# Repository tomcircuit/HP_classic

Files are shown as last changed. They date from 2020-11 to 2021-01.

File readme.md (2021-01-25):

# HP_classic - LiPo Battery for HP 'Classic' Calculators - Version 2
 
This is my attempt at a LiPo-based battery pack for "Classic" HP Calculators, specifically HP-35, HP-45, and HP-55.  The original NiCd packs are all dead by now, and rebuilding them is difficult - *assuming you can even find a pack to rebuild*. I thought it would be fun to use a rechargeable LiPo battery, and include the circuitry to re-charge via USB as well. 

> LiPo chemistry has very specific care-and-feeding when it comes to recharging, **you cannot use the HP AC charger to recharge this pack!**  Don't even try it with Version 1 of this project!

**UPDATE**: Version 2 design includes *Charger Immunity* circuitry to prevent mayhem if the HP AC  charger is connected. 

The basic idea is to use a gold-flashed (ENIG) PCB as the contact substrate, and mount the LiPo, USB micro B receptacle, and charging circuitry on the opposite side. The 'charger immunity' introduced in Version 2 is placed on the same side as the contact pads, but in areas where there will be no mechanical interference. A pair of laser-cut 'endcaps' locate the assembly within the battery well and allow the compartment cover to hold it in place. 
 
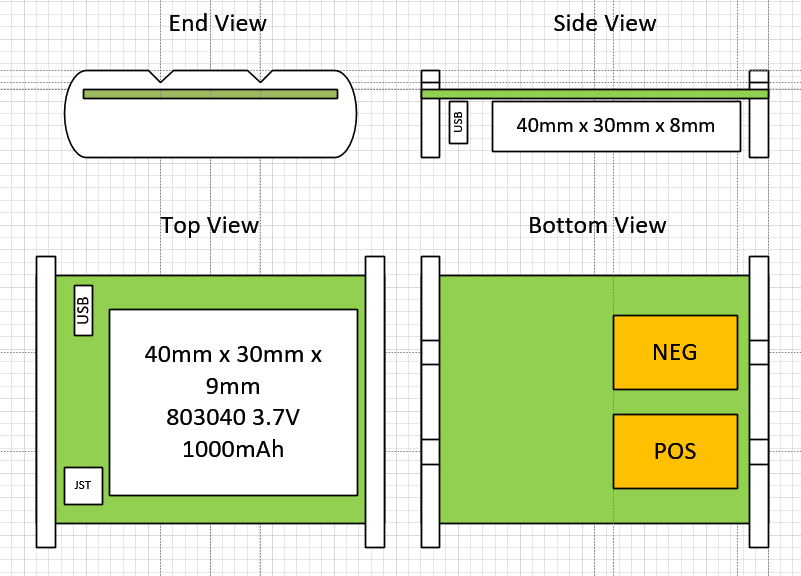
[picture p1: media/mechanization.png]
Mechanization


## The Endcaps
I just happen to have an original NiCd HP battery pack, so I was able to measure its end profile and draw it in MS Visio and export as an SVG file. The endcap is laser-cut from 3mm thick fiberboard and its overall size is **47mm x  14mm**. I'm sure you could use some other material if you desired. I went with fiberboard in case I needed to tweak it, and because it is cheap. Two endcaps are required for each pack. 

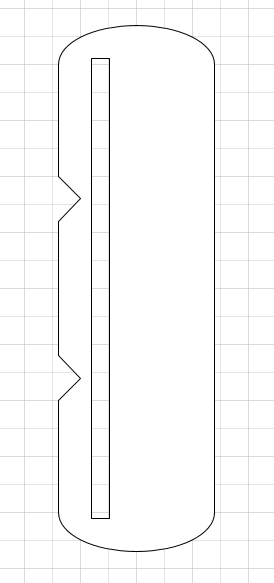
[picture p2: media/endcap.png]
Laser Cut Endcap


I had a batch of 6 pcs made by [Ponoko](https://www.ponoko.com/) and they were very inexpensive, less than $1 each. Consider that Ponoko has a flat $14 setup charge per design, however. If you have other means to access a laser cutter, you can probably do this much more cheaply.

## The PCB 
The PCB holds the USB micro B connector, the charging circuitry, the protection circuitry, a connector for the LiPo battery, and most importantly the pads that mate with the contacts in the calculator.  The overall size of the PCB is 56mm x 40mm. The material is 1.6mm thick FR4. So that the contact pads do not  tarnish over time, I chose a gold-flash treatment (ENIG). 

The schematic and PCB were designed using KiCAD. Note that the PCB can accommodate either a JST or 0.1" two pin battery connector type.

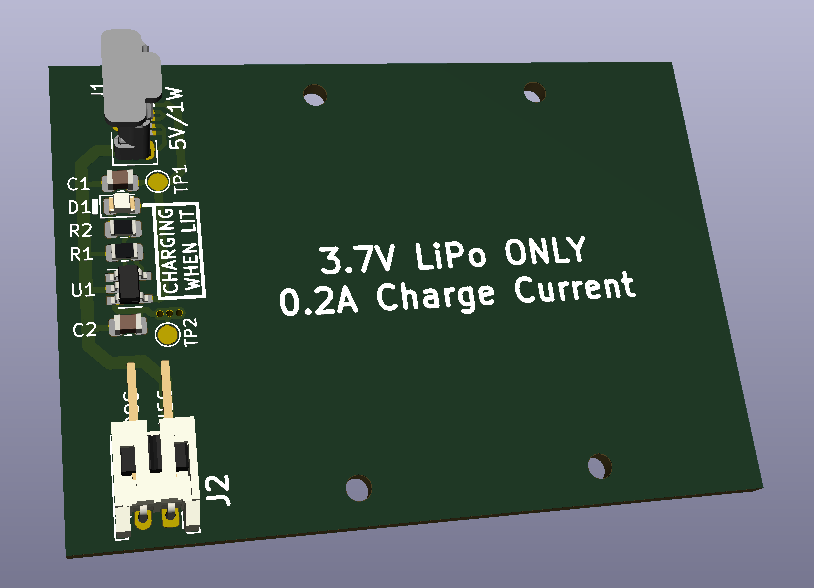
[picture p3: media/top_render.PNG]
3D render of PCB V2 top


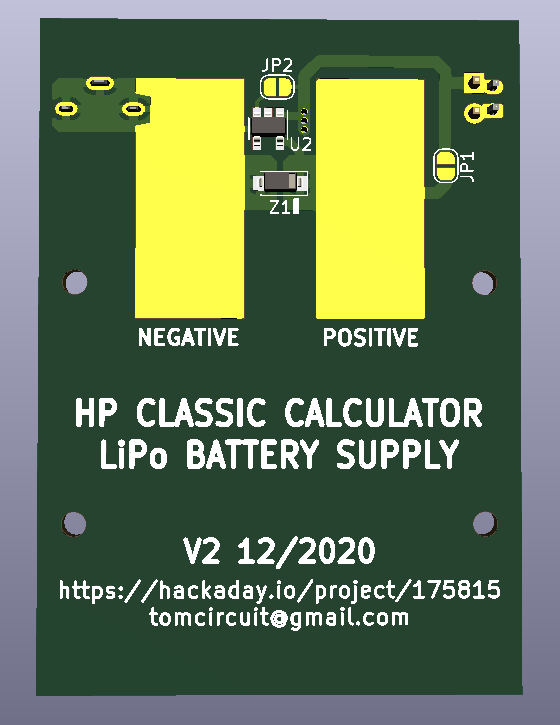
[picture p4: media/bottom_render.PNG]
3D render of PCB V2 bottom


I had the V1 PCB fabricated by [PCBWay](https://www.pcbway.com/)  This was the second PCB that I've had made by them, and I am once again very satisfied with the speed, quality, and price. The PCB can be ordered from them directly as a [shared project](https://www.pcbway.com/project/shareproject/HP_Classic_Calculator_LiPo_Battery_Pack.html). 

UPDATE: I will have the V2 PCB fabricated there, as well, and include a link when it's available.

## The LiPo Battery
I wanted a 1S (3.7V) LiPo battery in the neighborhood of 1000mAhr that would fit within the confines of the original pack envelope. This led me to a size "803040" LiPo battery. I prefer the JST connector, so I found one with that connector type. The PCB can accommodate either JST or "two pin" connectors, so there's some flexibility here. 

I believe that a thicker battery could be used, because of the profile of the battery compartment cover. That might allow for a higher capacity battery, which would translate into longer running time. 

**UPDATE**: I founda  1200mAhr LiPo battery in size "103040" that is just 2mm thicker. I've ordered some to try out.  20% more capacity is always good, right?

## Putting It All Together
Pretty self-explanatory. I used 0805 size components to allow for easy hand-soldering. Note that D1 is an LED and is polarized, so pay attention to that. Soldering the USB connector requires a fine-tip iron and some patience. 

The endcaps each need a small amount of Krazy glue to keep them in place, and the PCB edges should be flush with the outer surface of each endcap to match the overall size of the original battery pack.
> You will not be able to access the USB connector's solder joints after the endcap is installed, so be sure of your workmanship there before you glue that particular endcap in place

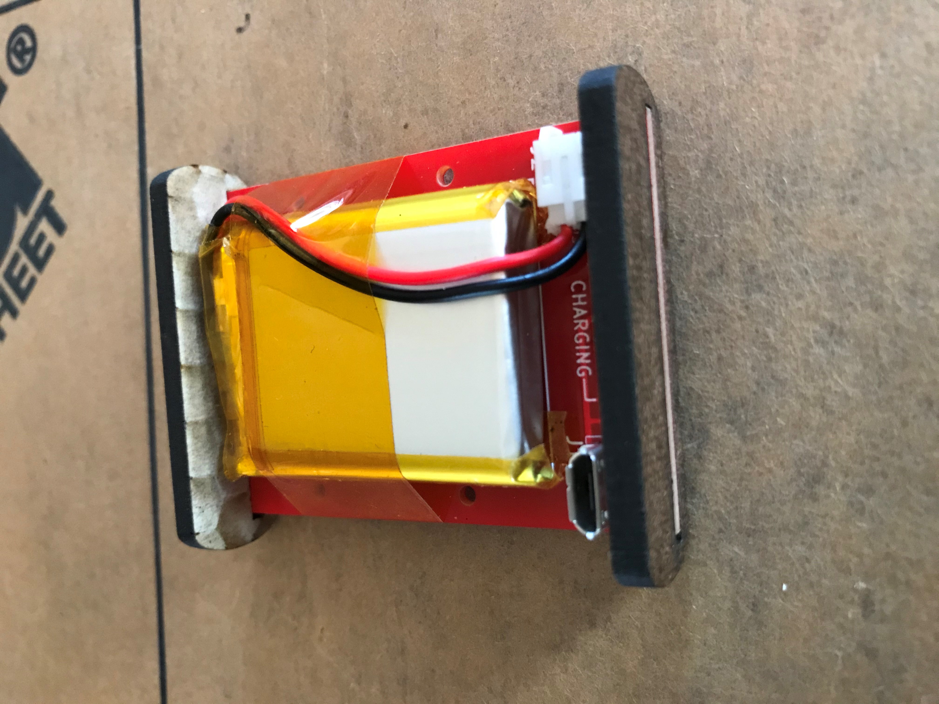
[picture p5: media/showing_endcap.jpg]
Assembly showing endcap


**UPDATE**: I've rotated the USB connector 180degrees on PCB V2, so that the solder joints can be accessed even after the endcap is glued on. It's still a good idea to wait until everything is tested before gluing on the endcaps, though.

I don't know if there are 'standards' for LiPo battery connector polarity, but I managed to get a battery that had the opposite pinning than what I expected. I had to swap the polarity of the battery plug to make it match PCB V1 pinout. Plug the battery in and tape it to the PCB. 

**UPDATE**: I've swapped the JST connector pins on PCB V2 so that they agree with all of the LiPo batteries that I could find photos of on the web.  This should make life easier for everyone in the future.

## Charge It
Connect a micro-B cable to the board and charge the LiPo battery. The LED will stay lit during the charging process, and extinguish when it is completed. The charge current is about 200mA (0.2C for a 1000mAhr battery). You can adjust R1 to change the current if you need to. It took about two hours to charge my battery,

## Use It!
Install the pack into the calculator, paying attention to mate the contact pads with the contacts in the calculator. The pads are sized to prevent contact if the pack is inserted incorrectly, but I do not recommend testing to find out if I got that all right or not. My understanding is that these classic calculators will not withstand reverse voltage. Don't risk it.
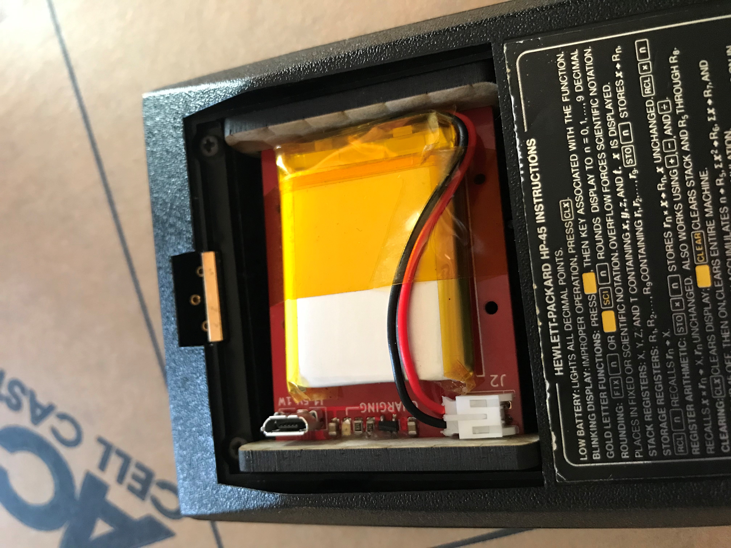
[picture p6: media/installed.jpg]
Installed Pack


If you've done everything correctly, you should be greeted with 0.00 when you turn your calculator on. Your classic calculator is now sipping power from a modern, convenient, and most importantly *non-leaking* battery pack.  Enjoy!

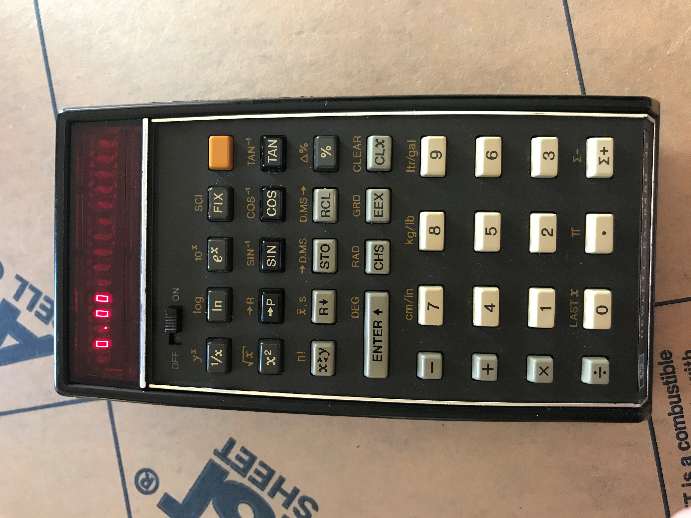
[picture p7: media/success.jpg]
Happy HP45


December 2, 2020
Tom LeMense
rev 2
<!--stackedit_data:
eyJoaXN0b3J5IjpbLTIzMjk3MDczOF19
-->

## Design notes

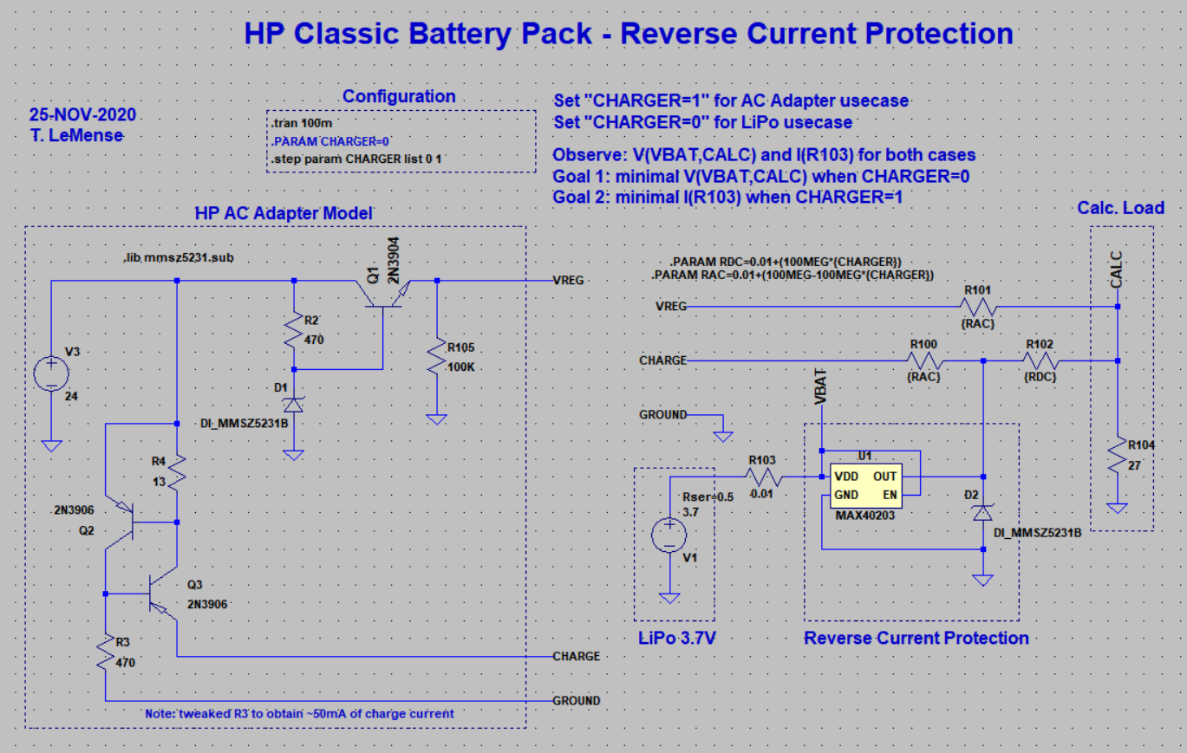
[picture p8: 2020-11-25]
simulation/schematic.png

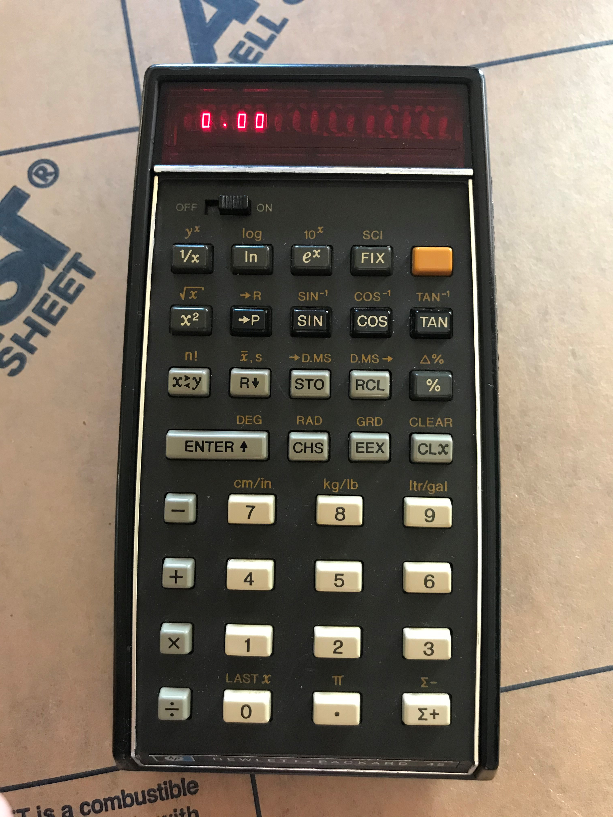
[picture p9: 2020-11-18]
media/success_rot.jpg

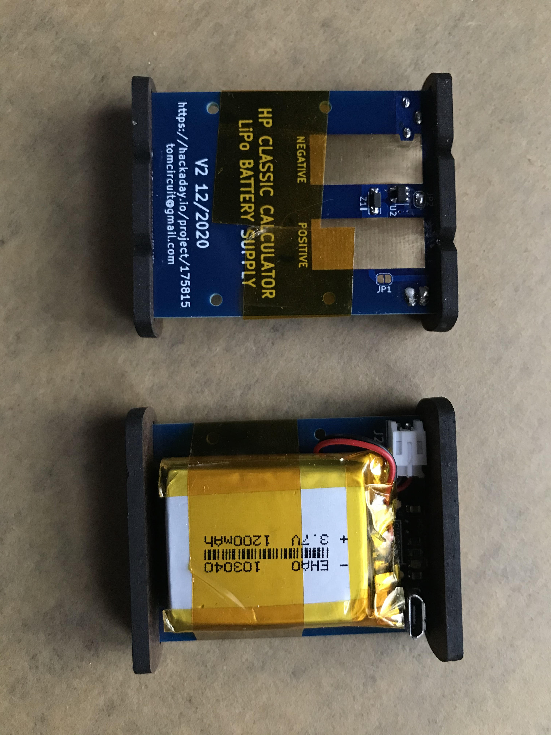
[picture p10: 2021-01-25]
media/v2_packs1.jpg

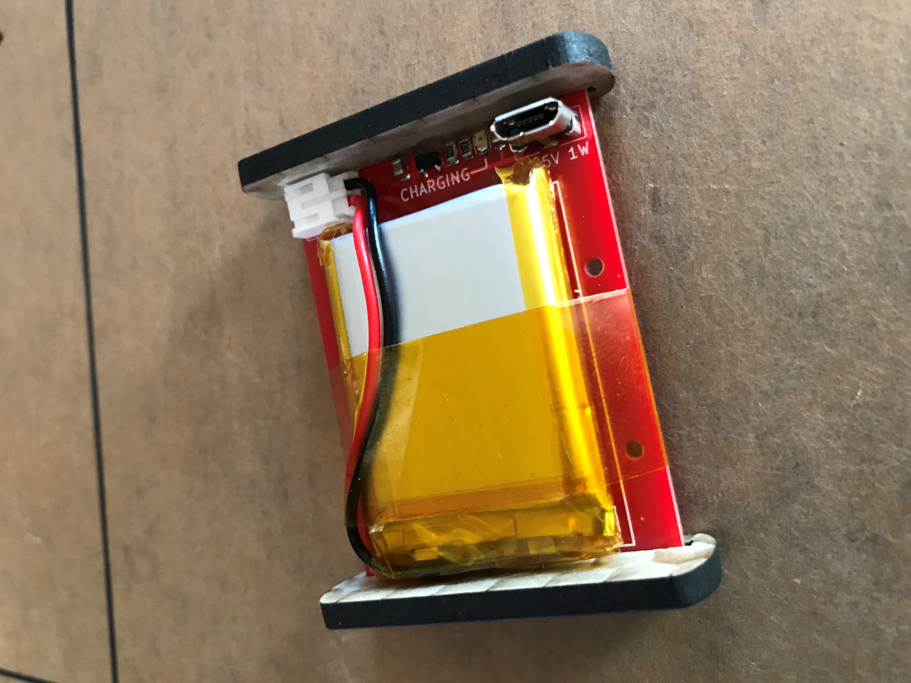
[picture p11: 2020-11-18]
media/top_oblique.jpg

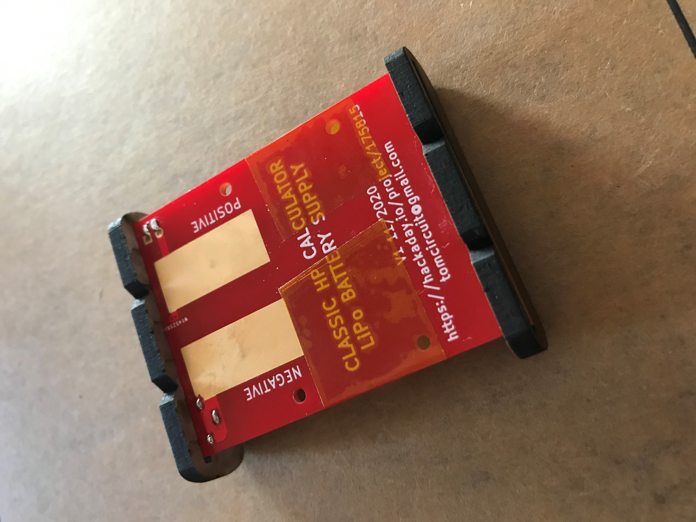
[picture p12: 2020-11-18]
media/under_oblique.jpg

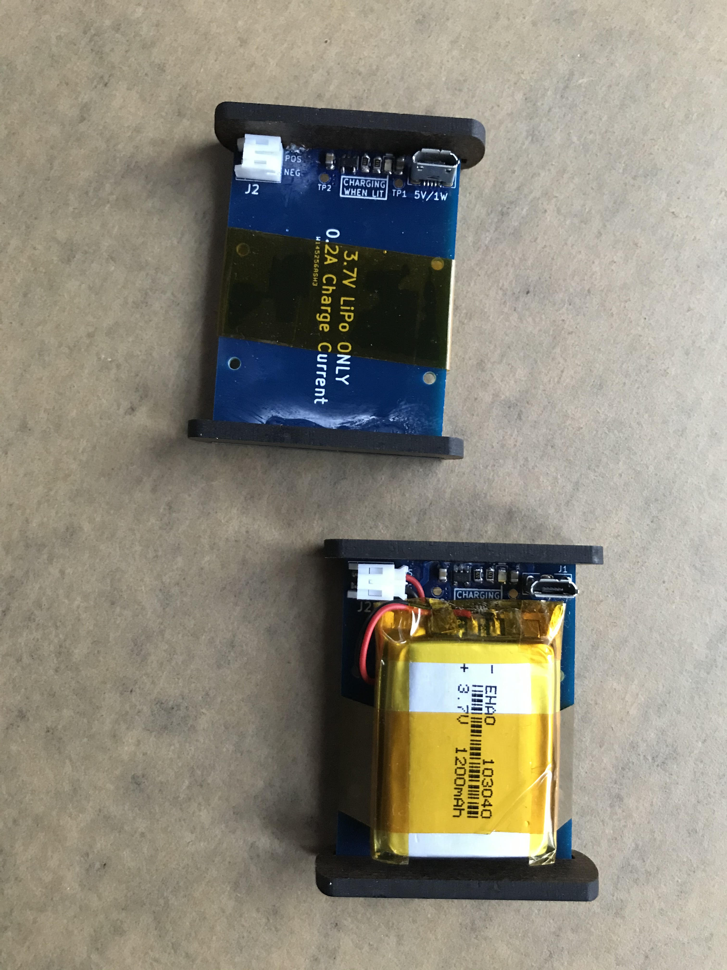
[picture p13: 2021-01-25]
media/v2_packs2.jpg

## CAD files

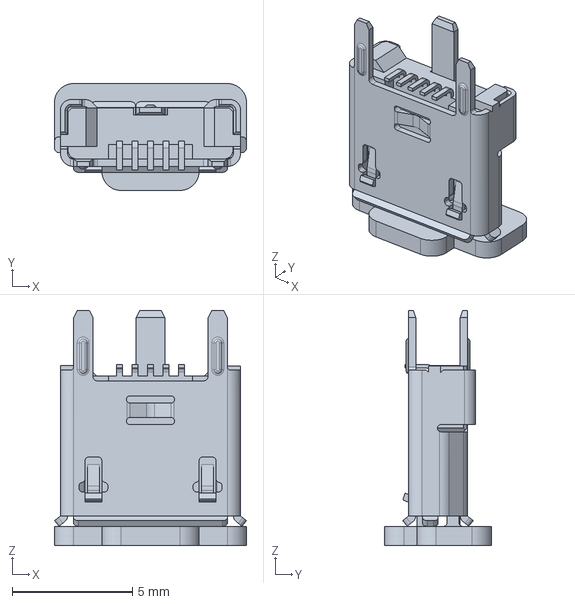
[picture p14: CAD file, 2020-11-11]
electrical/105133-0011_stp/1051330011.stp
8.00 x 4.45 x 9.78 mm

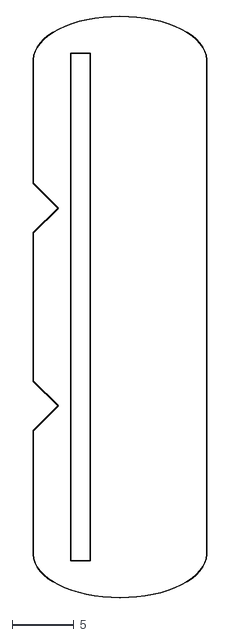
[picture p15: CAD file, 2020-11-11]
Mechanical/20201103_Classic_HP_mechanical.dxf
14.0 x 47.0

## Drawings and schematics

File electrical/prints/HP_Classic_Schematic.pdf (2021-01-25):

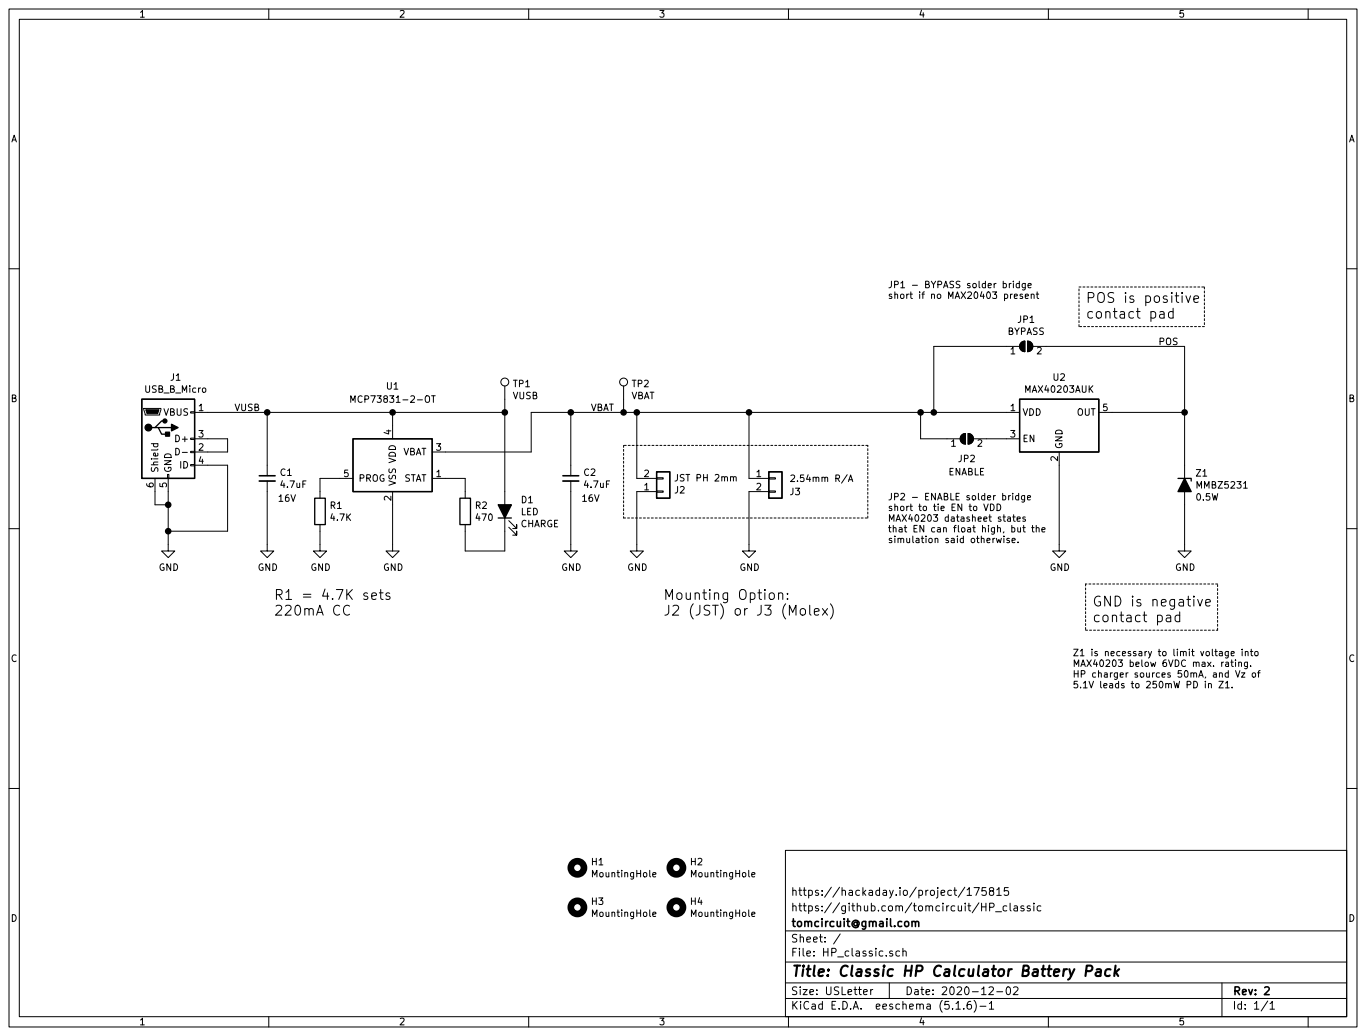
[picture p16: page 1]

HP charger sources 50mA, and Vz of 5.1V leads to 250mW PD in Z1. POS is positive
contact pad

simulation said otherwise. JP1 - BYPASS solder bridge
short if no MAX20403 present

JP2 - ENABLE solder bridge
short to tie EN to VDD MAX40203 datasheet states

that EN can float high, but the

https://hackaday.io/project/175815 H2MountingHole GND

Z1 is necessary to limit voltage into
MAX40203 below 6VDC max. rating.

https://github.com/tomcircuit/HP_classic
File: HP_classic.sch Sheet: / tomcircuit@gmail.com

Id: 1/1 Title: Classic HP Calculator Battery Pack

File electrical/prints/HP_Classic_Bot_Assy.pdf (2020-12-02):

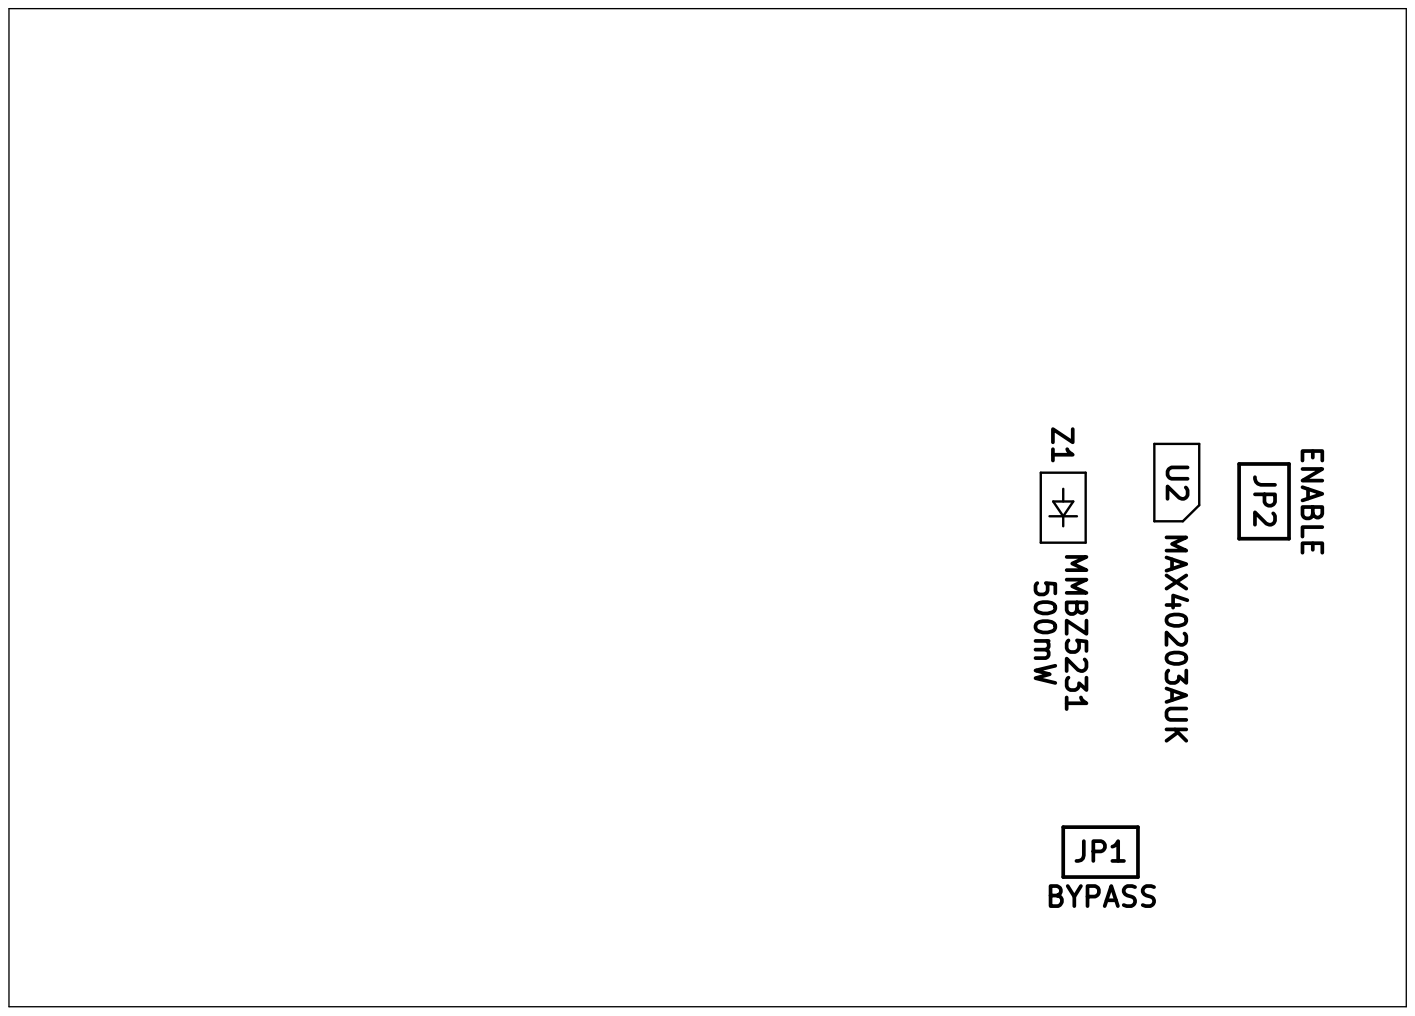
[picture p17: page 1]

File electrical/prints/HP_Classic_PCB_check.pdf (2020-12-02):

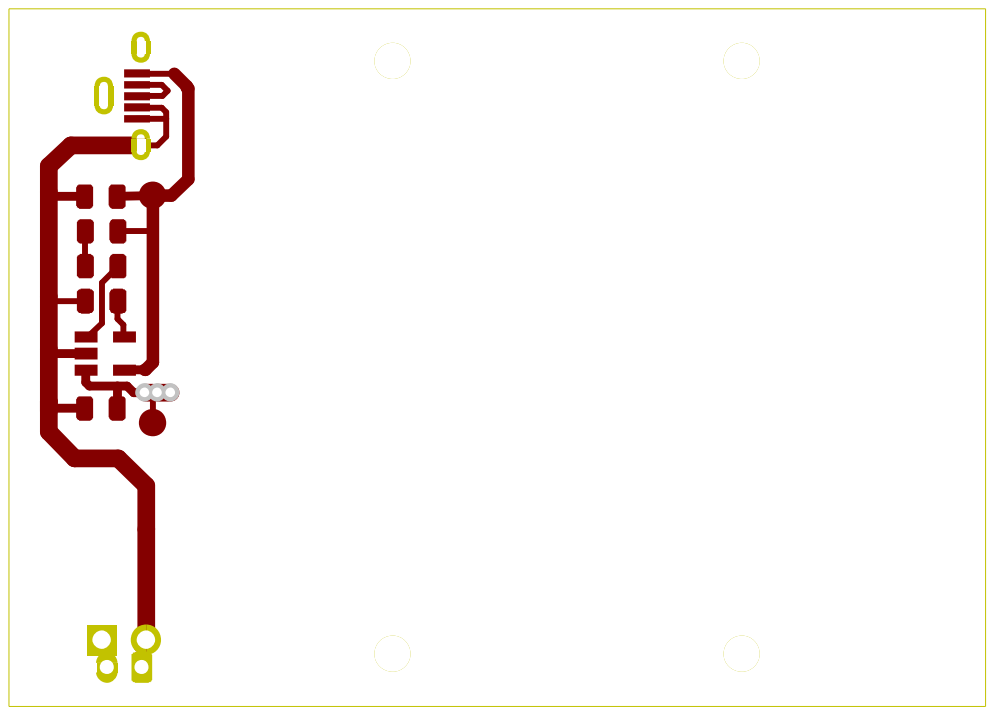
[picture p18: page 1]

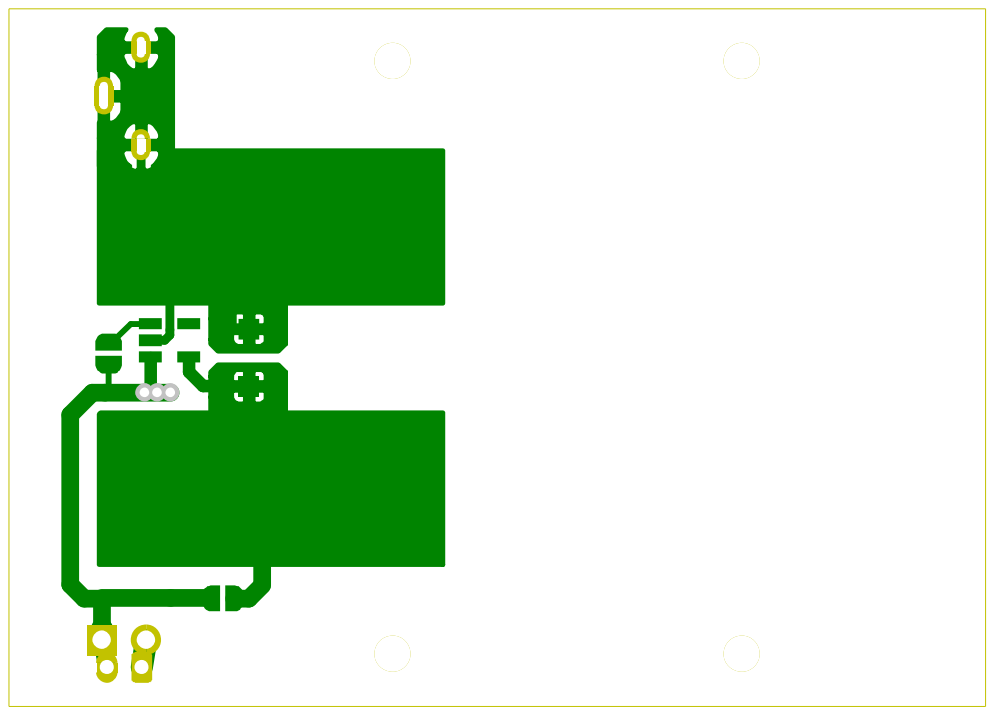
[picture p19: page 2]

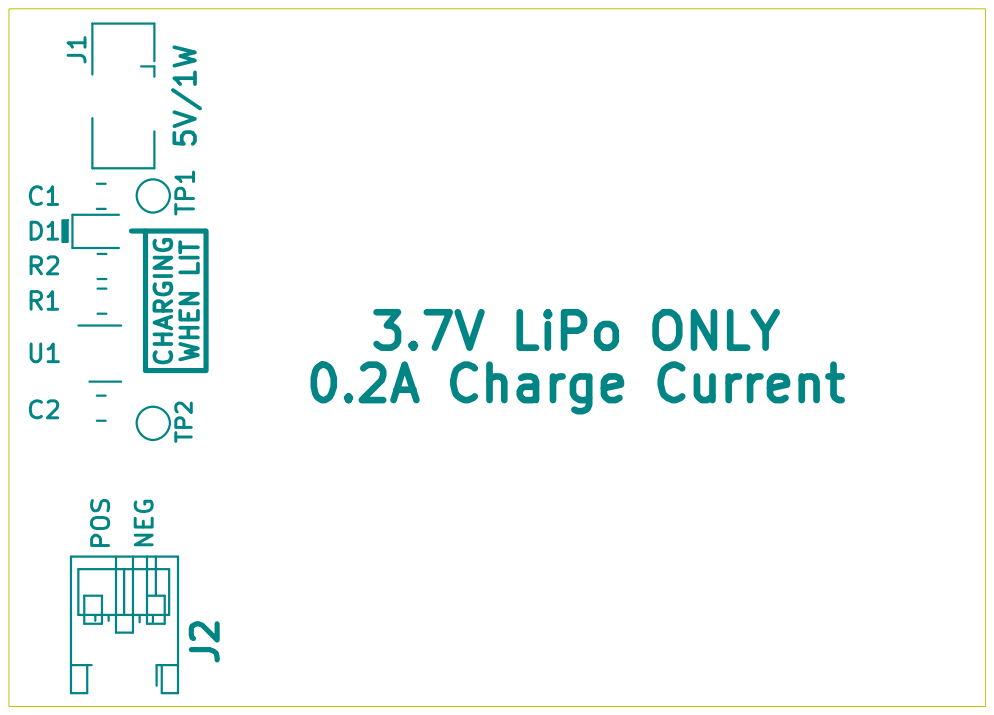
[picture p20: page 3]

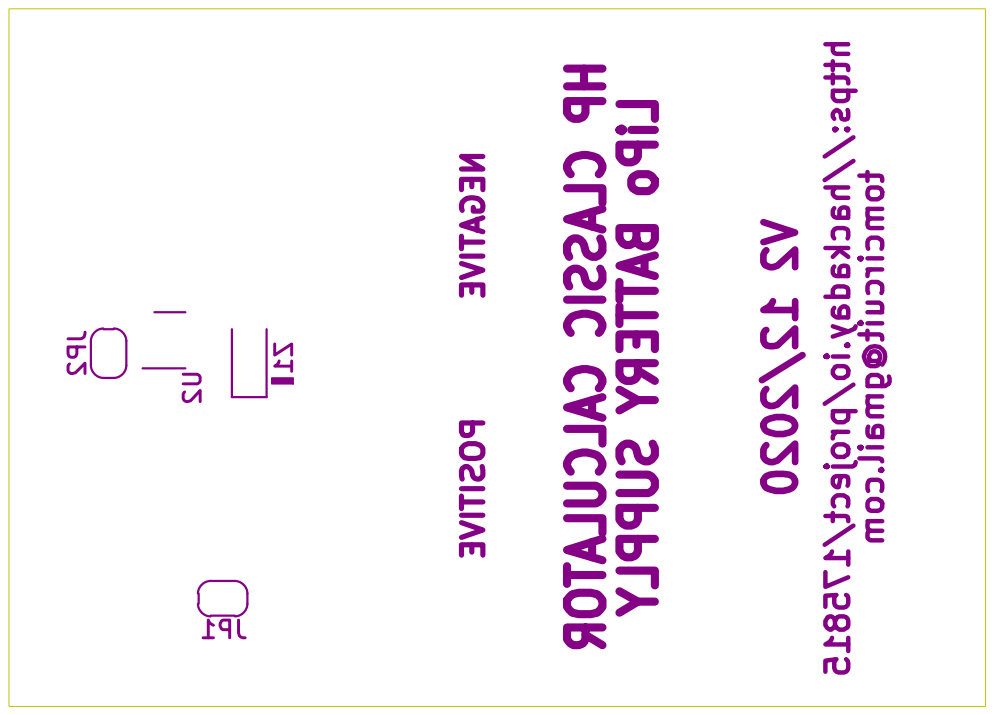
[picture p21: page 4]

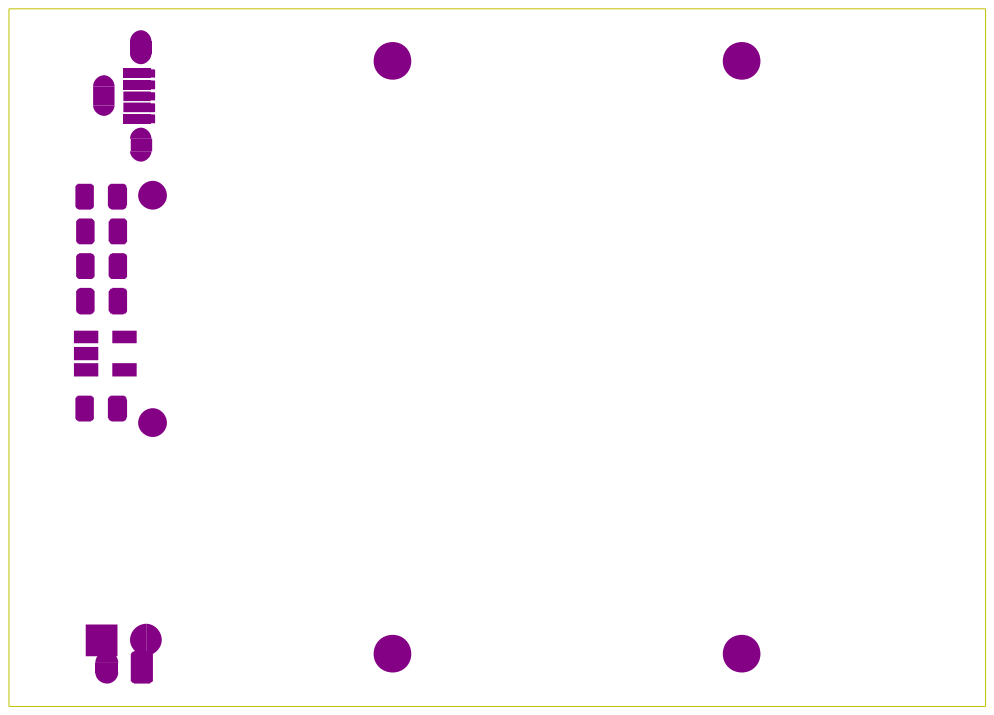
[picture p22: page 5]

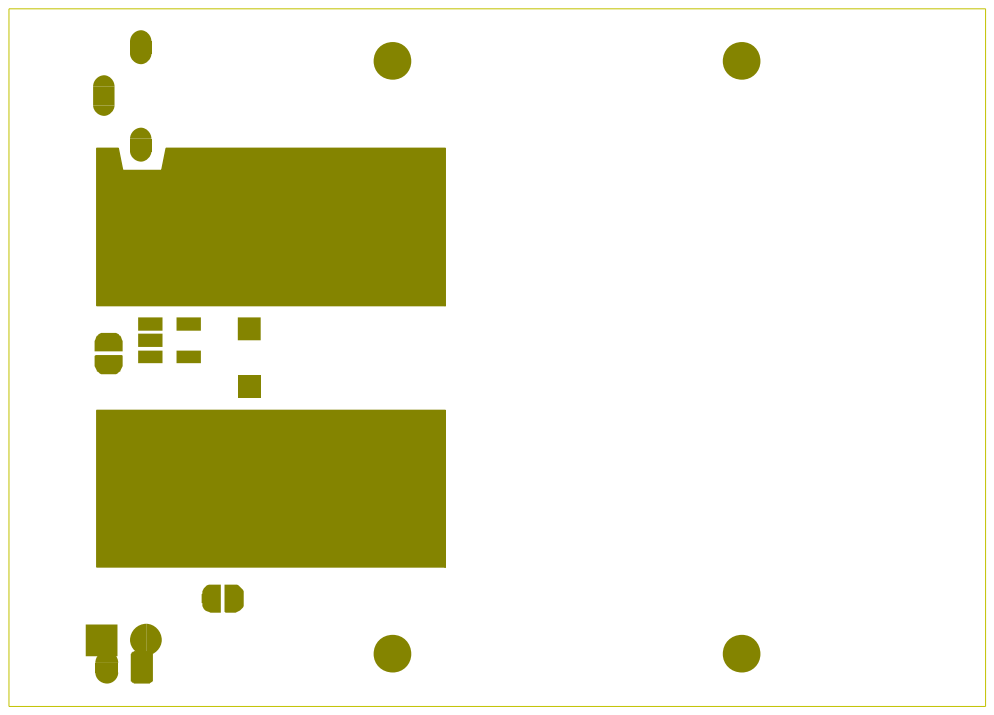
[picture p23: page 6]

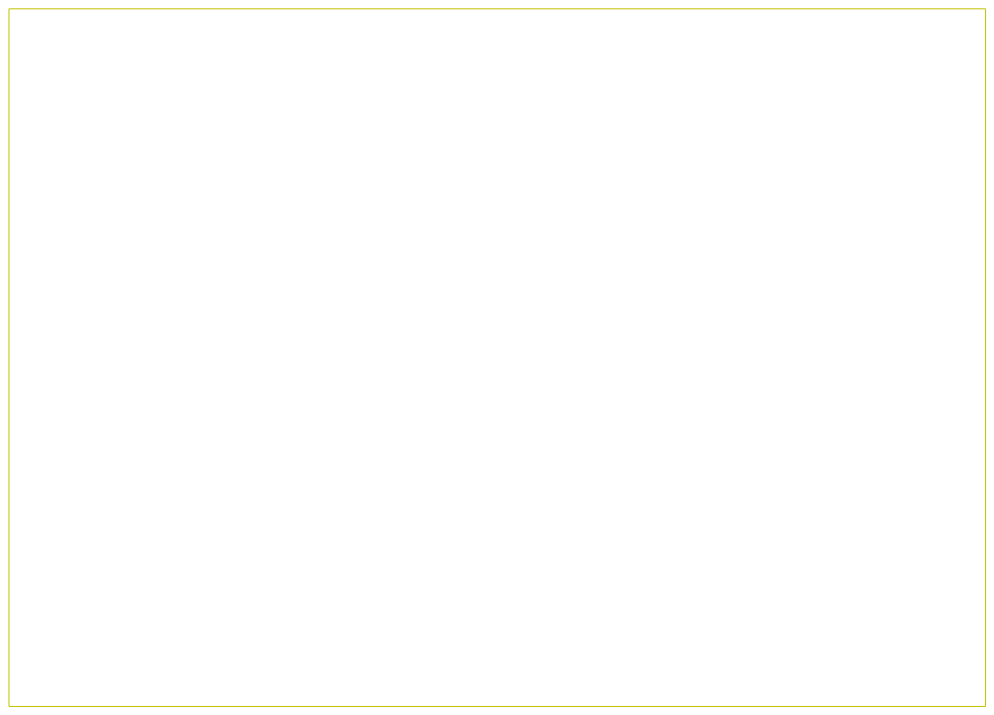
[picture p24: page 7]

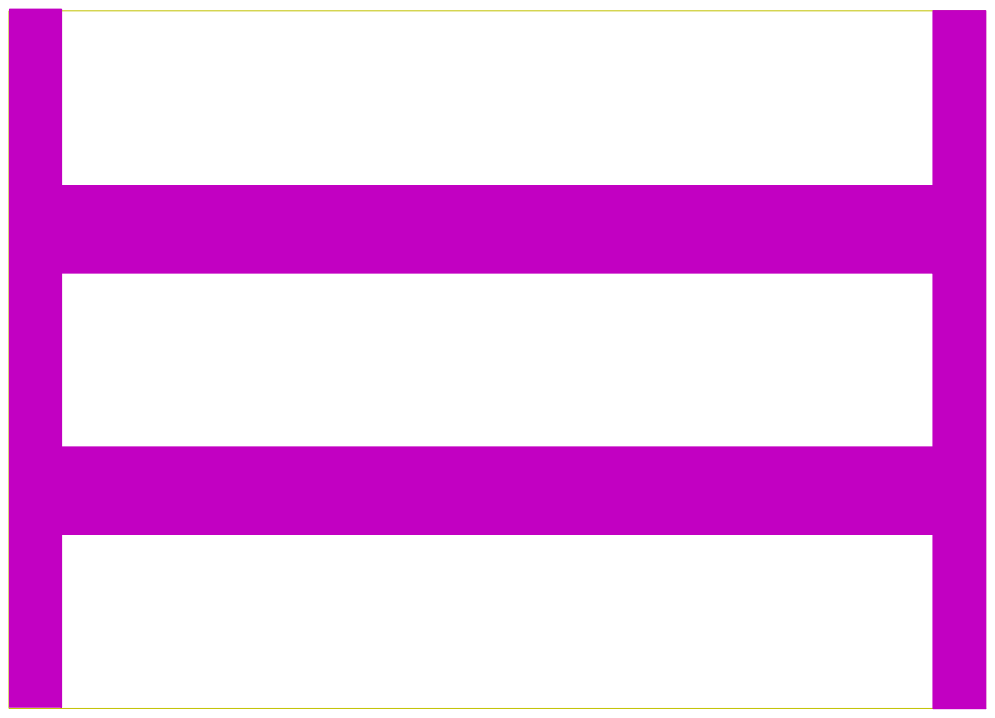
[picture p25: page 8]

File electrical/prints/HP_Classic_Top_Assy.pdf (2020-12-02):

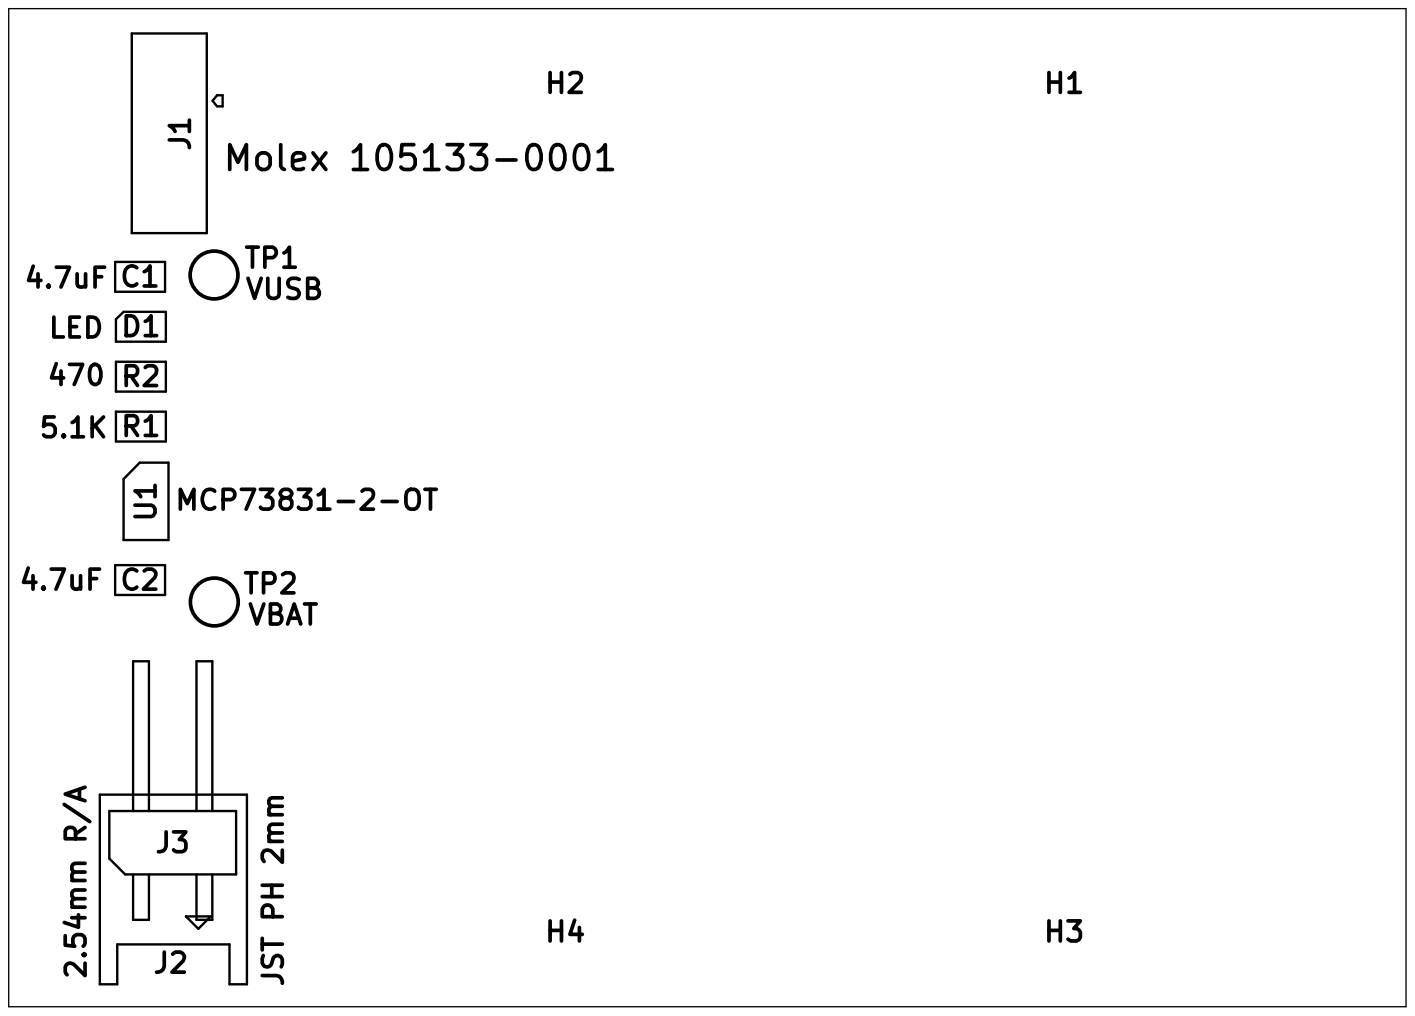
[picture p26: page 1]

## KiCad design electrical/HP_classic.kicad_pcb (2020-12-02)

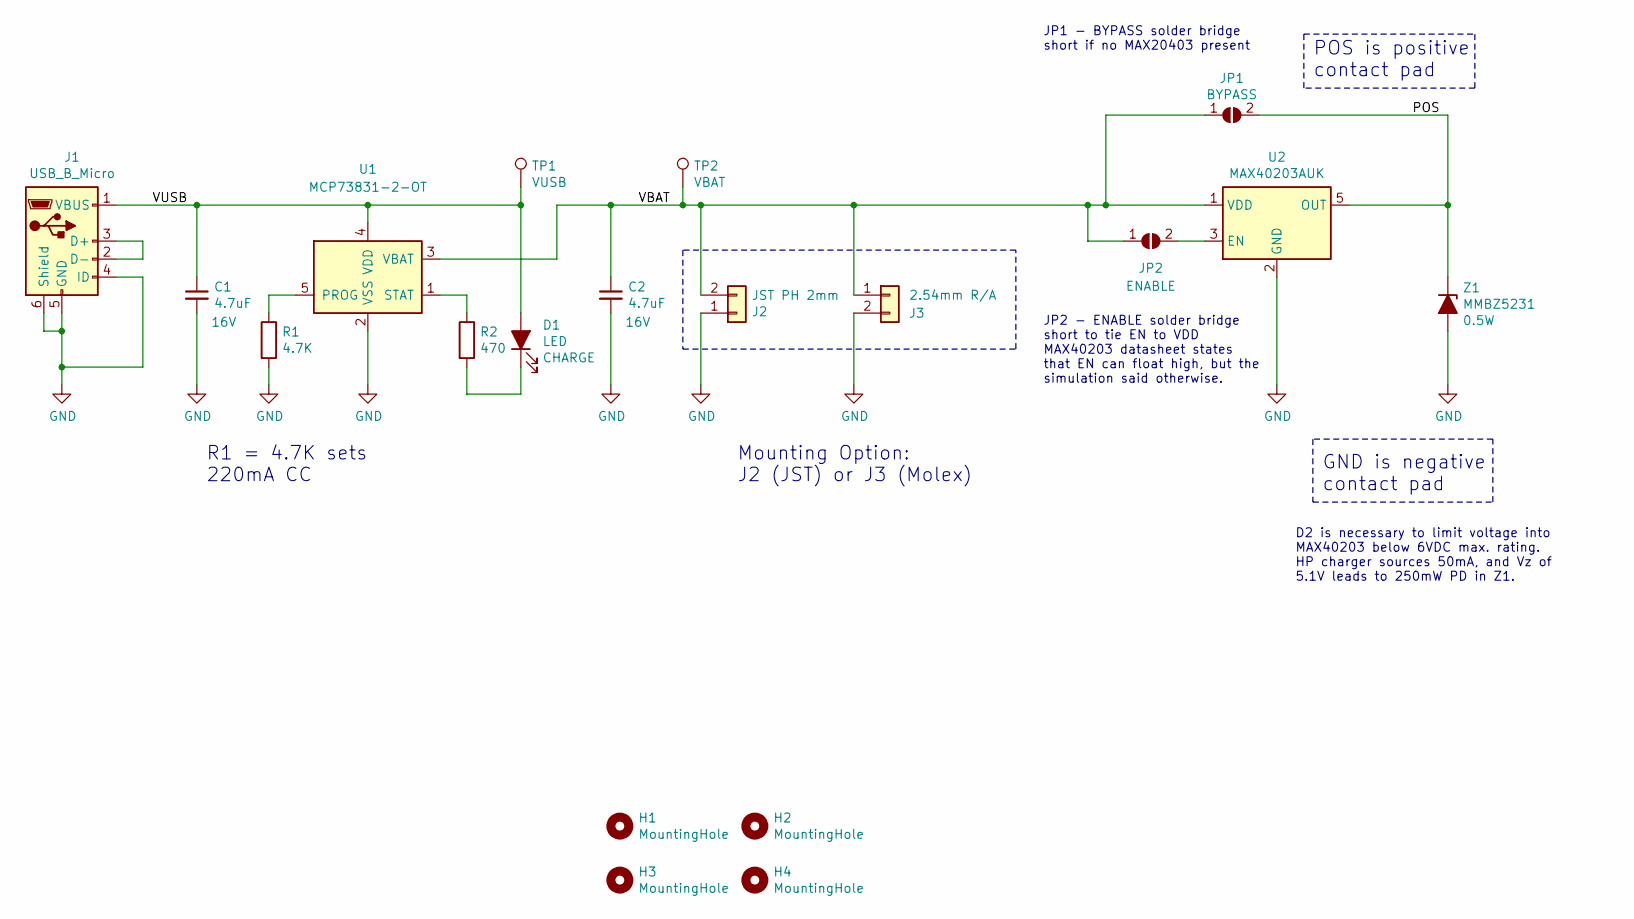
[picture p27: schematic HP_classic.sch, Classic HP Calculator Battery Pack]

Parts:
C1, C2: 4.7uF; C_0805_2012Metric; MPN MuRata GRM21BR71C475KE51L; DigiKey 490-14466-1-ND
D1: LED; LED_0805_2012Metric
H1, H2, H3, H4: MountingHole; MountingHole_2mm
J1: USB_B_Micro; USB_Micro-B_Molex-105133-0001; MPN Molex 1051330011; DigiKey WM10134CT-ND
J2: JST PH 2mm; JST_PH_S2B-PH-K_1x02_P2.00mm_Horizontal; MPN S2B-PH-K-S(LF)(SN); DigiKey 455-1719-ND
J3: 2.54mm R/A; PinHeader_1x02_P2.54mm_Horizontal
JP1: BYPASS; SolderJumper-2_P1.3mm_Open_RoundedPad1.0x1.5mm
JP2: ENABLE; SolderJumper-2_P1.3mm_Open_RoundedPad1.0x1.5mm
R1: 4.7K; R_0805_2012Metric
R2: 470; R_0805_2012Metric
TP1: VUSB; TestPoint_Pad_D1.5mm
TP2: VBAT; TestPoint_Pad_D1.5mm
U1: MCP73831-2-OT; SOT-23-5; MPN Microchip MCP73831T-2ACI/OT; DigiKey MCP73831T-2ACI/OTCT-ND
U2: MAX40203AUK; SOT-23-5; DigiKey 175-MAX40203AUK+TCT-ND
Z1: MMBZ5231; D_SOD-123; DigiKey MMSZ5231B-FDICT-ND

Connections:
/POS: JP1.2 (B), U2.5 (OUT), Z1.1 (K)
/VBAT: C2.1, J2.2, J3.1, JP1.1 (A), JP2.1 (A), TP2.1, U1.3 (VBAT), U2.1 (VDD)
/VUSB: C1.1, D1.2 (A), J1.1 (VBUS), TP1.1, U1.4 (VDD)
GND: C1.2, C2.2, J1.4 (ID), J1.5 (GND), J1.6 (Shield), J2.1, J3.2, R1.2, U1.2 (VSS), U2.2 (GND), Z1.2 (A)
unnamed: D1.1 (K), R2.2
unnamed: J1.2 (D-), J1.3 (D+)
unnamed: JP2.2 (B), U2.3 (EN)
unnamed: R1.1, U1.5 (PROG)
unnamed: R2.1, U1.1 (STAT)

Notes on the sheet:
Mounting Option: J2 (JST) or J3 (Molex)
R1 = 4.7K sets 220mA CC
POS is positive contact pad
GND is negative contact pad
D2 is necessary to limit voltage into MAX40203 below 6VDC max. rating. HP charger sources 50mA, and Vz of 5.1V leads to 250mW PD in Z1.
JP2 - ENABLE solder bridge short to tie EN to VDD MAX40203 datasheet states that EN can float high, but the simulation said otherwise.
JP1 - BYPASS solder bridge short if no MAX20403 present

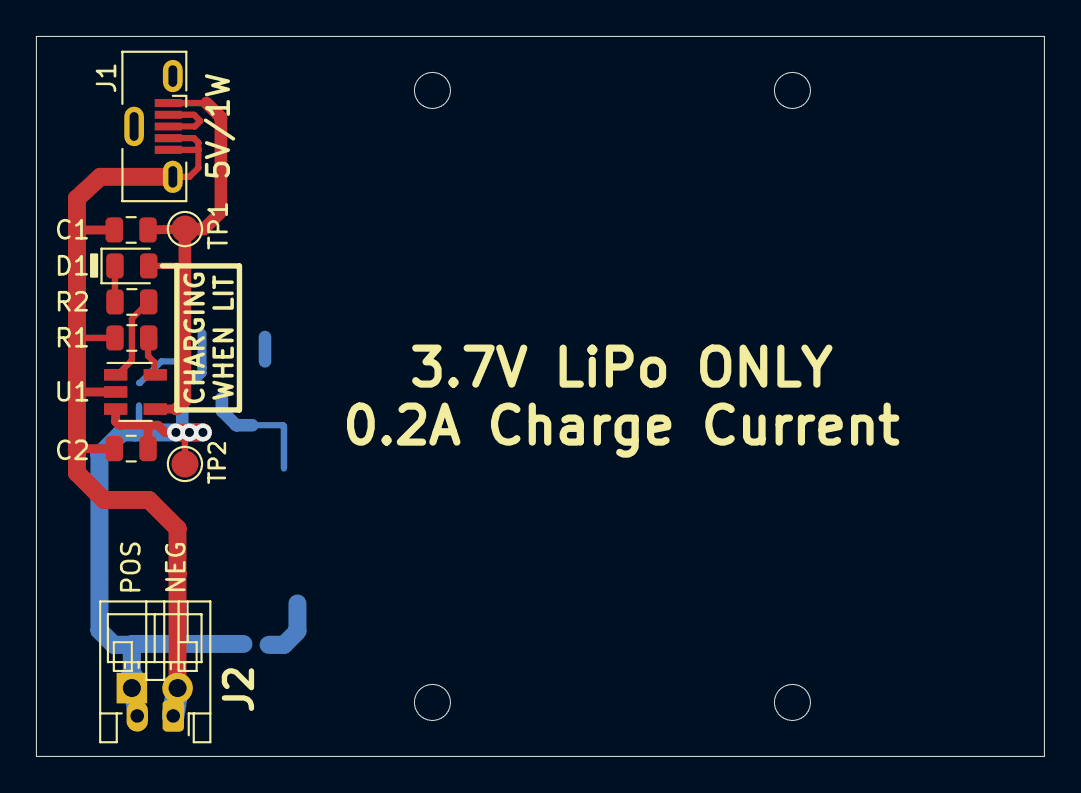
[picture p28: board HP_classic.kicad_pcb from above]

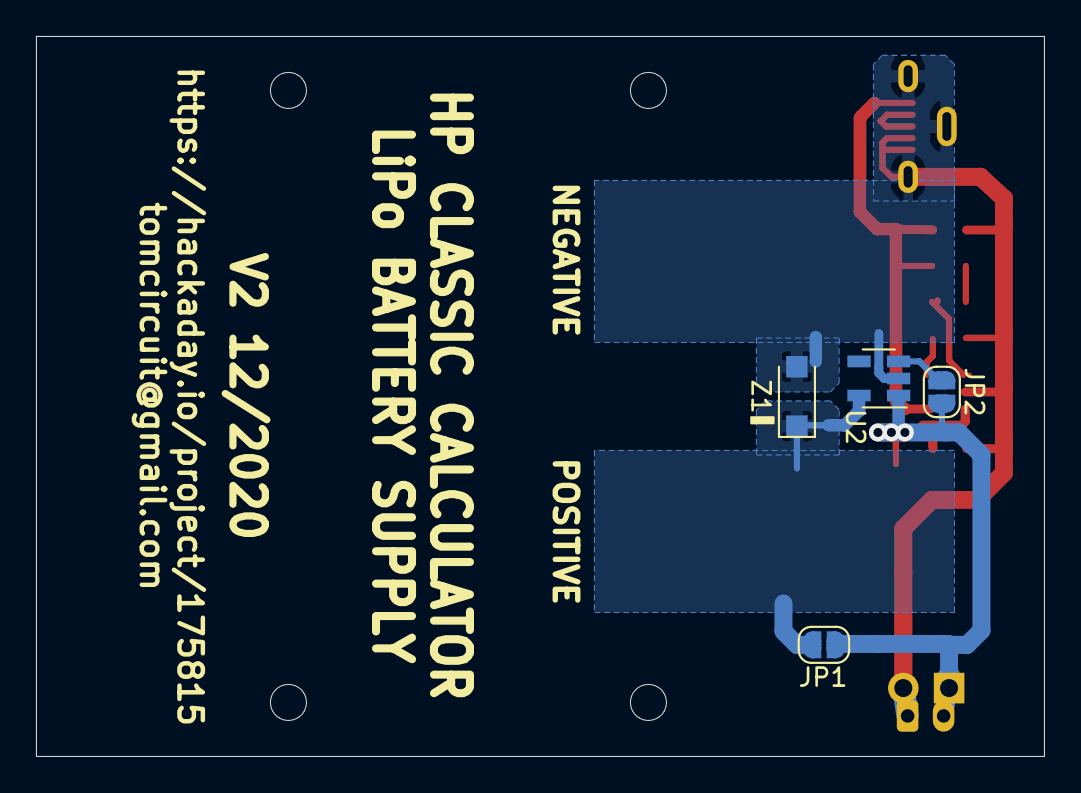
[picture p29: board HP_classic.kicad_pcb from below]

Board: 2 copper layers, 56.0 x 40.0 mm, 19 parts (4 on the bottom side), 9 nets.

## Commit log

2020-11-18 Version 1 Checkin
    Schematic updated with component details
    PCB udpated for plot formatting
    Check plots generated
    Interactive BOM generated
    [20201103_Classic_HP_PCB outline.dxf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]
2020-11-18 Rev 1 release
    bumped rev to 1 on schematic. generated PDF schematic file.
    [HP_classic.sch]
2020-11-25 Added simulation on MAX40203 ideal diode
    Simuation in LTspice on MAX40203 'ideal diode' reverse current protection for LiPo cell when HP AC adapter is connected. This will prevent the HP charger from attempting to 'trickle charge' the LiPo cell, by blocking the current. A 5.1V zener clamp keeps the charger output voltage within the 6V spec of the MAX40203.
2020-12-02 upload version 2 ecad and updates
    Upload of v2 KiCad schematic, PCB, and BOM information. V2 includes protection circuitry to prevent damage if an HP charger is attached while this pack is installed in the calculator.
    [HP_classic-B_Cu.gbr, HP_classic-B_Mask.gbr, HP_classic-B_SilkS.gbr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]
2021-01-24 added photos of V2 board
2021-01-25 Corrected note on schematic
    Note describing Zener Z1 referred to D2. There is no D2, only Z1.
